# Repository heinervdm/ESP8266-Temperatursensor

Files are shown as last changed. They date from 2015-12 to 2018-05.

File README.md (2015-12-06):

# ESP8266-Temperatursensor
Wifi temperature sensor based on the Espressif ESP8266 Wifi module and the Dallas DS18X20 temperature sensor

For this project it is assumed, that the ESP8266 is configured for deep sleep. For e.g. ESP-01 one needs to patch to PCB, for ESP-03 one has to close the solder jumper neer pin 8.

To compile you have to adjust the paths in the Makefile and copy user_config.h.template to user_config.h and adjust the defines inside.
I'm using a hardcoded IP address because the DNS was not working very well for me and therefore consumes to much power.

The Firmware will read all connected DS18X20 sensors (A define in user_config.h determines the maximum amount of sensors) and will call a the path: /index.php?value[]=...&uid[]=...&... with the read temperature and the uid of the corresponding sensor, as well as the current supply voltage of the ESP8266 module and it's mac address as uid.

# This is based on the following projects:

DS18X20 readout: http://siwawi.bauing.uni-kl.de/avr_projects/tempsensor/

Makefile & user_main structure: https://github.com/esp8266/source-code-examples

ESP8266 eagle footprint: https://github.com/wvanvlaenderen/ESP8266-Eagle_Library

Javascript plotting: https://github.com/dima117/Chart.Scatter

BMP180 readout: https://github.com/reaper7/esp8266_i2c_bmp180

DHT11/22 readout: https://github.com/mathew-hall/esp8266-dht

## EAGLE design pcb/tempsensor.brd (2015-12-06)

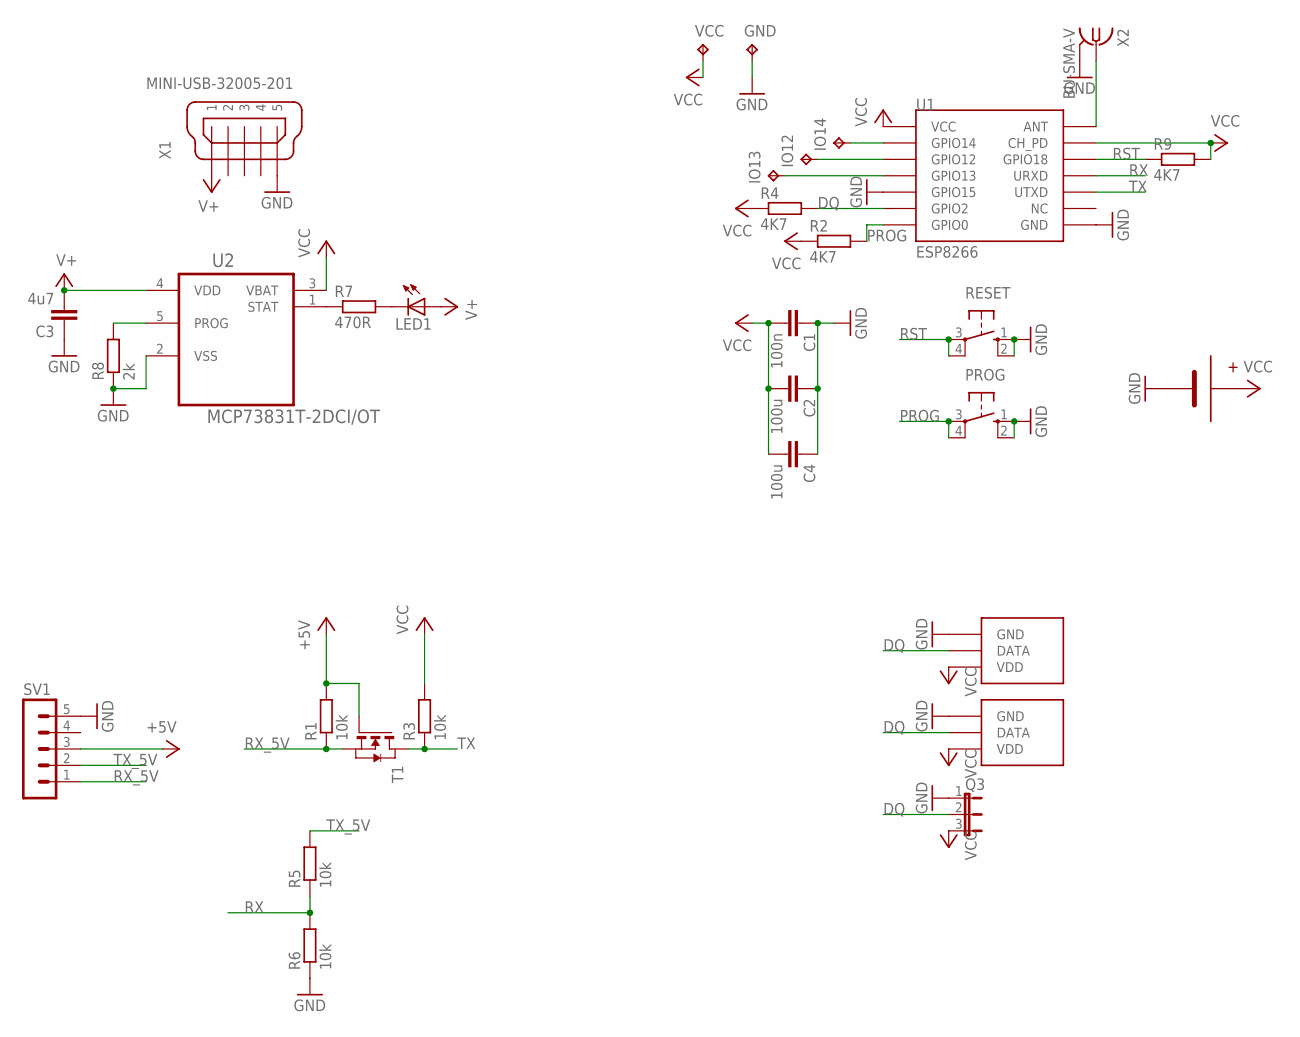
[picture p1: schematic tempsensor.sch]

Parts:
C1: 100n; C0805
C2, C4: 100u; C1206
C3: 4u7; C0805
GND: TPPAD1-13; P1-13
IO12, IO13, IO14: TPPAD1-13; P1-13
LED1: LEDCHIPLED_0805; CHIPLED_0805
PROG: 10-XX; B3F-10XX
Q1: DS18X20TO92; TO92
Q2: DS18X20SO-8; SO08WIDE
Q3: JP2E; JP2
R1, R3, R5, R6: 10k; M0805
R2, R4, R9: 4K7; M0805
R7: 470R; M0805
R8: 2k; M0805
RESET: 10-XX; B3F-10XX
SV1: MA05-1
T1: NMOSSOT23; SOT-23
U1: ESP8266; ESP-03
U2: MCP73831T-2DCI/OT; SOT95P270X145-5N
U$2: 18650-BATTERHOLDERHA1X18650; HA1X18650
VCC: TPPAD1-13; P1-13
X1: MINI-USB-32005-201; 32005-201
X2: BU-SMA-V

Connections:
+5V: R1.2, SV1.3, T1.3 (G)
DQ: Q1.2 (DATA), Q2.4 (DATA), Q3.2, R4.2, U1.GPIO2
GND: C1.1, C2.1, C3.1, C4.1, GND.TP, PROG.1 (S), PROG.2 (S1), Q1.3 (GND), Q2.5 (GND), Q3.1, R6.1, R8.1, RESET.1 (S), RESET.2 (S1), SV1.5, U1.GND, U1.GPIO15, U2.2 (VSS), U$2.P$1, X1.5, X2.2, X2.3 (2), X2.4 (2), X2.5 (2)
unnamed: R7.1, U2.1 (STAT)
unnamed: IO13.TP, U1.GPIO13
unnamed: IO12.TP, U1.GPIO12
unnamed: IO14.TP, U1.GPIO14
unnamed: LED1.C, R7.2
unnamed: R8.2, U2.5 (PROG)
unnamed: U1.ANT, X2.1
PROG: PROG.3, PROG.4 (P1), R2.2, U1.GPIO0
RST: R9.1, RESET.3, RESET.4 (P1), U1.GPIO18
RX: R5.1, R6.2, U1.URXD
RX_5V: R1.1, SV1.1, T1.2 (S)
TX: R3.1, T1.1 (D), U1.UTXD
TX_5V: R5.2, SV1.2
V+: C3.2, LED1.A, U2.4 (VDD), X1.1
VCC: C1.2, C2.2, C4.2, Q1.1 (VDD), Q2.3 (VDD), Q3.3, R2.1, R3.2, R4.1, R9.2, U1.CH_PD, U1.VCC, U2.3 (VBAT), U$2.P$2, VCC.TP

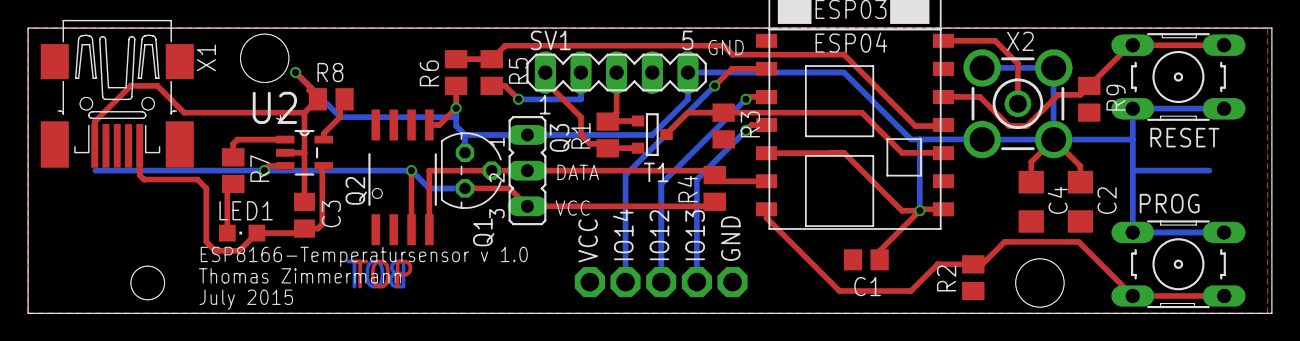
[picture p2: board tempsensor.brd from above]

Board: 2 copper layers, 88.6 x 20.3 mm, 31 parts (1 on the bottom side), 18 nets.

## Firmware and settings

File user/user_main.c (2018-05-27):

#include "ets_sys.h"
#include "osapi.h"
#include "gpio.h"
#include "os_type.h"
#include "user_config.h"
#include "user_interface.h"
#include "stdout.h"
#include "espmissingincludes.h"
#include "espconn.h"
#include "ip_addr.h"
#include "mem.h"

#include "ds18x20.h"
#include "onewire.h"

#ifdef READ_BMP
#include "i2c.h"
#include "i2c_bmp180.h"
#endif

#ifdef READ_DHT
#include "dht.h"
#endif

#ifdef READ_ADS1115
#include "i2c_ads1115.h"
#endif

// #define user_procTaskPrio        0
// #define user_procTaskQueueLen    1

uint8_t gSensorIDs[MAXSENSORS][OW_ROMCODE_SIZE];
// os_event_t    user_procTaskQueue[user_procTaskQueueLen];
static os_timer_t fail_timer;

unsigned char *default_certificate;
unsigned int default_certificate_len = 0;
unsigned char *default_private_key;
unsigned int default_private_key_len = 0;

void ICACHE_FLASH_ATTR getHexStr(char *buf, uint8_t *arr, uint8_t size) {
	uint8_t i=0;
	for (;i<size;i++) {
		uint8_t b = (arr[i] >> 4) & 0x0F;
		if (b > 9) {
			b += 'A'-10;
		}
		else {
			b+= '0';
		}
		buf[i*2]=b;
		b = (arr[i]) & 0x0F;
		if (b > 9) {
			b += 'A'-10;
		}
		else {
			b+= '0';
		}
		buf[i*2+1]=b;
	}
	buf[size*2] = '\0';
}

static uint8_t ICACHE_FLASH_ATTR search_sensors(void) {
	uint8_t i;
	uint8_t id[OW_ROMCODE_SIZE];
	uint8_t diff, nSensors;

	os_printf("Scanning Bus for DS18X20\n");

	ow_reset();

	nSensors = 0;

	diff = OW_SEARCH_FIRST;
	while ( diff != OW_LAST_DEVICE && nSensors < MAXSENSORS ) {
		DS18X20_find_sensor( &diff, &id[0] );

		if( diff == OW_PRESENCE_ERR ) {
			os_printf( "No Sensor found\n" );
			break;
		}

		if( diff == OW_DATA_ERR ) {
			os_printf( "Bus Error\n" );
			break;
		}

		for ( i=0; i < OW_ROMCODE_SIZE; i++ )
			gSensorIDs[nSensors][i] = id[i];

		nSensors++;
	}

	return nSensors;
}

int32_t ICACHE_FLASH_ATTR getTemperature(uint8_t sensor) {
	int32_t temp;

	if ( DS18X20_start_meas( DS18X20_POWER_EXTERN, &gSensorIDs[sensor][0] ) == DS18X20_OK ) {
		for (uint16 i = 0; i < DS18B20_TCONV_12BIT; i++) {
			os_delay_us(1000);
		}
		if ( DS18X20_read_maxres( &gSensorIDs[sensor][0], &temp) != DS18X20_OK ) {
			os_printf("DS18X20: crc error\n");
		}
	}
	else {
		os_printf("DS18X20: failed (short circuit?)");
	}
	char buf[OW_ROMCODE_SIZE*2];
	getHexStr(&buf[0], &gSensorIDs[sensor][0], OW_ROMCODE_SIZE);
	os_printf("Sensor: %d, Temperature: %d, ID: %s\n", sensor, temp, buf);

	return temp;
}

static void ICACHE_FLASH_ATTR disconnect_callback(void * arg) {
	struct espconn *conn = (struct espconn *)arg;
	
	if(conn != NULL) {
		if(conn->proto.tcp != NULL) {
			os_free(conn->proto.tcp);
		}
		os_free(conn);
	}

	// No Wifi after wake up, we will start it manually
// 	system_deep_sleep_set_option(4);
	system_deep_sleep(1000*1000*60*5);
}

static void ICACHE_FLASH_ATTR receive_callback(void * arg, char * buf, unsigned short len) {
	buf[len-1] = 0;
	os_printf("%s", buf);
}

static void ICACHE_FLASH_ATTR sent_callback(void * arg) {
	os_delay_us(1);
}

static void ICACHE_FLASH_ATTR error_callback(void *arg, sint8 errType) {
	disconnect_callback(arg);
}

static void ICACHE_FLASH_ATTR connect_callback(void * arg) {
	struct espconn * conn = (struct espconn *)arg;
	espconn_regist_recvcb(conn, receive_callback);
	espconn_regist_sentcb(conn, sent_callback);
	os_delay_us(1);

	char macstr[2*6+2];
	uint8_t mac[6];
	wifi_get_macaddr(STATION_IF,&mac[0]);
	getHexStr(&macstr[0],&mac[0],6);
	os_printf("Got MAC addr: %s\n", macstr);

	char buf1[(MAXSENSORS+5)*50];
#ifdef READ_1W
	uint8_t n = search_sensors();
	char buf2[50];
	char uid[OW_ROMCODE_SIZE*2+2];
	for (uint8_t i = 0; i < n;i++) {
		int32_t temp = getTemperature(i);
		getHexStr(&uid[0],&gSensorIDs[i][0],OW_ROMCODE_SIZE);
		os_sprintf(buf2,"&value[]=%d.%04d&uid[]=%s",temp/10000,temp%10000,uid);
		os_strcat(buf1, buf2);
		os_delay_us(1);
	}
#endif
#ifdef READ_BMP
i2c_init();
bool ret = BMP180_Init();
if (ret == 1) {
	char buf2[50];
	uint32_t pressure = BMP180_GetVal(GET_BMP_REAL_PRESSURE);
	os_sprintf(buf2,"&value[]=%d.%02d&uid[]=%s%s",pressure/100,pressure%100,macstr,"/pres");
	os_strcat(buf1, buf2);
	os_delay_us(1);
	uint32_t temperature = BMP180_GetVal(GET_BMP_TEMPERATURE);
	os_sprintf(buf2,"&value[]=%d.%01d&uid[]=%s%s",temperature/10,temperature%10,macstr,"/prestemp");
	os_strcat(buf1, buf2);
	os_delay_us(1);
	uint32_t relpressure = BMP180_GetVal(GET_BMP_RELATIVE_PRESSURE);
	os_sprintf(buf2,"&value[]=%d.%02d&uid[]=%s%s",relpressure/100,relpressure%100,macstr,"/presrel");
	os_strcat(buf1, buf2);
	os_delay_us(1);
} else {
	os_printf("BMP180: init couldn't read version register.\n");
}
#endif
#ifdef READ_DHT
	DHTInit(DHT_TYPE,0);
	struct sensor_reading* result = readDHT(1);
	if (result->success == 1) {
		char buf2[50];
		os_sprintf(buf2,"&value[]=%d&uid[]=%s%s",(int)(result->temperature),macstr,"/humiditytemp");
		os_strcat(buf1, buf2);
		os_delay_us(1);
		os_sprintf(buf2,"&value[]=%d&uid[]=%s%s",(int)(result->humidity),macstr,"/humidity");
		os_strcat(buf1, buf2);
		os_delay_us(1);
	}
#endif
#ifdef READ_ADS1115
	ADS1115_init();
	uint16_t adsres = ADS1115_readRawValue();
	{
		char buf2[50];
		os_sprintf(buf2,"&value[]=%ul&uid[]=%s%s",adsres,macstr,"/ph");
		os_strcat(buf1, buf2);
		os_delay_us(1);
	}
#endif
	float v = readvdd33();
// 	float v = system_get_vdd33();
	v /= 1024.;
	os_printf("Got power reading: %d.%02d\n", (int)v, (int)((v-(int)v)*100));
	if (v < 3) {
		// I don't know if i can really shut it off this way but it's the best way i've found.
		os_printf("Truning off to protect the battery from exhaustive discharge\n");
		system_deep_sleep(0);
	}
	os_delay_us(1);

	char buf[400+MAXSENSORS*50];
	int len = os_sprintf(buf,
						"GET /index.php?uid[]=%s&value[]=%d.%02d%s HTTP/1.1\r\n"
						"Host: " HOSTNAME ":%d\r\n"
						"Connection: close\r\n"
						"User-Agent: ESP8266\r\n"
						EXTRA_HEADER "\r\n",
					macstr, (int)v, (int)((v-(int)v)*100), buf1, PORT);
	espconn_sent(conn, (uint8_t *)buf, len);
}

static void ICACHE_FLASH_ATTR fail_timerfunc(void *arg) {
	os_printf("Connect seems to have failed. Going to sleep and trying again in 5 minutes.\n");
	system_deep_sleep(1000*1000*60*5);
}

static void ICACHE_FLASH_ATTR some_timerfunc(void *arg) {
	ip_addr_t addr;
	IPADDR(&addr);

	struct espconn * conn = (struct espconn *)os_malloc(sizeof(struct espconn));
	conn->type = ESPCONN_TCP;
	conn->state = ESPCONN_NONE;
	conn->proto.tcp = (esp_tcp *)os_malloc(sizeof(esp_tcp));
	conn->proto.tcp->local_port = espconn_port();
	conn->proto.tcp->remote_port = 80;
	
	os_memcpy(conn->proto.tcp->remote_ip, &addr, 4);

	espconn_regist_connectcb(conn, connect_callback);
	espconn_regist_disconcb(conn, disconnect_callback);
	espconn_regist_reconcb(conn, error_callback);
	espconn_connect(conn);
}


void ICACHE_FLASH_ATTR wifi_handle_event_cb(System_Event_t *evt) {
	os_printf("event %x\n", evt->event);
	switch (evt->event) {
		case EVENT_STAMODE_CONNECTED:
			os_printf("connect to ssid %s, channel %d\n",
					  evt->event_info.connected.ssid,
			 evt->event_info.connected.channel);
			break;
		case EVENT_STAMODE_DISCONNECTED:
			os_printf("disconnect from ssid %s, reason %d\n",
					  evt->event_info.disconnected.ssid,
			 evt->event_info.disconnected.reason);
			break;
		case EVENT_STAMODE_AUTHMODE_CHANGE:
			os_printf("mode: %d -> %d\n",
					  evt->event_info.auth_change.old_mode,
			 evt->event_info.auth_change.new_mode);
			break;
		case EVENT_STAMODE_GOT_IP:
			// Connection done, disable fail timer
			os_timer_disarm(&fail_timer);
			os_printf("ip:" IPSTR ",mask:" IPSTR ",gw:" IPSTR,
					  IP2STR(&evt->event_info.got_ip.ip),
					  IP2STR(&evt->event_info.got_ip.mask),
					  IP2STR(&evt->event_info.got_ip.gw));
			os_printf("\n");

			os_delay_us(1);
			some_timerfunc(NULL);
			break;
		default:
			break;
	}
}

void ICACHE_FLASH_ATTR init_done(void) {
	os_printf("Init done!\n");

	// Start fail timer, if we have no ip within 10 seconds, go to sleep again
	os_timer_disarm(&fail_timer);
	os_timer_setfn(&fail_timer, (os_timer_func_t *)fail_timerfunc, NULL);
	os_timer_arm(&fail_timer, 1000*10, 0);

	char ssid[32] = SSID;
	char password[64] = SSID_PASSWORD;
	struct station_config stationConf;
	// Set station mode
	wifi_set_opmode(STATION_MODE);

	// Don't check the mac addr
	stationConf.bssid_set = 0; 
	// Set ap settings
	os_memcpy(&stationConf.ssid, ssid, 32);
	os_memcpy(&stationConf.password, password, 64);
	wifi_station_set_config(&stationConf);
	wifi_station_disconnect();
	wifi_set_event_handler_cb(&wifi_handle_event_cb);
	os_printf("Connecting to Wifi\n");
	wifi_station_connect();
}

//Init function 
void ICACHE_FLASH_ATTR user_init() {
	stdoutInit();
	system_init_done_cb(init_done);
}

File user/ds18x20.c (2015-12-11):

/*********************************************************************************
Title:    DS18X20-Functions via One-Wire-Bus
Author:   Martin Thomas <eversmith@heizung-thomas.de>   
          http://www.siwawi.arubi.uni-kl.de/avr-projects
Software: avr-gcc 4.3.3 / avr-libc 1.6.7 (WinAVR 3/2010) 
Hardware: any AVR - tested with ATmega16/ATmega32/ATmega324P and 3 DS18B20

ported to esp8266 by Thomas Zimmermann (bugs(at)vdm-design.de)

Partly based on code from Peter Dannegger and others.

changelog:
20041124 - Extended measurements for DS18(S)20 contributed by Carsten Foss (CFO)
200502xx - function DS18X20_read_meas_single
20050310 - DS18x20 EEPROM functions (can be disabled to save flash-memory)
           (DS18X20_EEPROMSUPPORT in ds18x20.h)
20100625 - removed inner returns, added static function for read scratchpad
         . replaced full-celcius and fractbit method with decicelsius
           and maxres (degreeCelsius*10e-4) functions, renamed eeprom-functions,
           delay in recall_e2 replaced by timeout-handling
20100714 - ow_command_skip_last_recovery used for parasite-powerd devices so the
           strong pull-up can be enabled in time even with longer OW recovery times
20110209 - fix in DS18X20_format_from_maxres() by Marian Kulesza
2015ß719 - ported to ESP8266
**********************************************************************************/

#include "ds18x20.h"
#include "onewire.h"
#include "crc8.h"
#include "ets_sys.h"
#include "espmissingincludes.h"
#include "osapi.h"
#include "os_type.h"
#include "user_interface.h"
#include "stdout.h"

/*----------- start of "debug-functions" ---------------*/

#if DS18X20_VERBOSE
#if (!DS18X20_DECICELSIUS)
#error "DS18X20_DECICELSIUS must be enabled for verbose-mode"
#endif

static int16_t DS18X20_rawo_decicelsius( uint8_t fc, uint8_t sp[] );

char*  ICACHE_FLASH_ATTR itoa(int i, char b[])   // Convert Integer to ASCII!!
{
	char const digit[] = "0123456789";
	char* p = b;
	if(i<0){
		*p++ = '-';
		i *= -1;
	}
	int shifter = i;
	do{ //Move to where representation ends
		++p;
		shifter = shifter/10;
	}
	while(shifter);
	*p = '\0';
	do{ //Move back, inserting digits as u go
		*--p = digit[i%10];
		i = i/10;
	}
	while(i);
	return b;
}

void ICACHE_FLASH_ATTR DS18X20_show_id_uart( uint8_t *id, size_t n ) 
{
	size_t i;

	for( i = 0; i < n; i++ ) {
		if ( i == 0 ) { os_printf( "FC:" ); }
		else if ( i == n-1 ) { os_printf( "CRC:" ); }
		if ( i == 1 ) { os_printf( "SN: " ); }
		os_printf("%x",(id[i]));
		os_printf(" ");
		if ( i == 0 ) {
			if ( id[0] == DS18S20_FAMILY_CODE ) { os_printf ("(18S)"); }
			else if ( id[0] == DS18B20_FAMILY_CODE ) { os_printf ("(18B)"); }
			else if ( id[0] == DS1822_FAMILY_CODE ) { os_printf ("(22)"); }
			else { os_printf("( ? )"); }
		}
	}
	if ( crc8( id, OW_ROMCODE_SIZE) )
		os_printf( " CRC FAIL " );
	else 
		os_printf( " CRC O.K. " );
}

static void ICACHE_FLASH_ATTR show_sp_uart( uint8_t *sp, size_t n ) 
{
	size_t i;

	os_printf( "SP:" );
	for( i = 0; i < n; i++ ) {
		if ( i == n-1 ) { os_printf( "CRC:" ); }
		os_printf("%x",(sp[i]));
		os_printf(" ");
	}
}

/* 
   convert raw value from DS18x20 to Celsius
   input is: 
   - familycode fc (0x10/0x28 see header)
   - scratchpad-buffer
   output is:
   - cel full celsius
   - fractions of celsius in millicelsius*(10^-1)/625 (the 4 LS-Bits)
   - subzero =0 positiv / 1 negativ
   always returns  DS18X20_OK
*/
static uint8_t ICACHE_FLASH_ATTR DS18X20_measo_cel( uint8_t fc, uint8_t *sp, 
	uint8_t* subzero, uint8_t* cel, uint8_t* cel_frac_bits) 
{
	uint16_t meas;
	uint8_t  i;
	
	meas = sp[0];  // LSB
	meas |= ( (uint16_t)sp[1] ) << 8; // MSB
	
	//  only work on 12bit-base
	if( fc == DS18S20_FAMILY_CODE ) { // 9 -> 12 bit if 18S20
		/* Extended res. measurements for DS18S20 contributed by Carsten Foss */
		meas &= (uint16_t) 0xfffe;    // Discard LSB, needed for later extended precicion calc
		meas <<= 3;                   // Convert to 12-bit, now degrees are in 1/16 degrees units
		meas += ( 16 - sp[6] ) - 4;   // Add the compensation and remember to subtract 0.25 degree (4/16)
	}
	
	// check for negative 
	if ( meas & 0x8000 )  {
		*subzero=1;      // mark negative
		meas ^= 0xffff;  // convert to positive => (twos complement)++
		meas++;
	}
	else {
		*subzero=0;
	}
	
	// clear undefined bits for B != 12bit
	if ( fc == DS18B20_FAMILY_CODE || fc == DS1822_FAMILY_CODE ) {
		i = sp[DS18B20_CONF_REG];
		if ( (i & DS18B20_12_BIT) == DS18B20_12_BIT ) { ; }
		else if ( (i & DS18B20_11_BIT) == DS18B20_11_BIT ) {
			meas &= ~(DS18B20_11_BIT_UNDF);
		} else if ( (i & DS18B20_10_BIT) == DS18B20_10_BIT ) {
			meas &= ~(DS18B20_10_BIT_UNDF);
		} else { // if ( (i & DS18B20_9_BIT) == DS18B20_9_BIT ) { 
			meas &= ~(DS18B20_9_BIT_UNDF);
		}
	}
	
	*cel  = (uint8_t)(meas >> 4); 
	*cel_frac_bits = (uint8_t)(meas & 0x000F);
	
	return DS18X20_OK;
}

static void ICACHE_FLASH_ATTR DS18X20_uart_putemp(const uint8_t subzero, 
	const uint8_t cel, const uint8_t cel_frac_bits) 
{
	char buffer[sizeof(int)*8+1];
	size_t i;
	
	os_printf("%c",((subzero)?'-':'+'));
	os_printf("%d",(int)cel);
	os_printf(".");
	itoa(cel_frac_bits*DS18X20_FRACCONV,buffer);
	for ( i = 0; i < 4-strlen(buffer); i++ ) {
		os_printf("0");
	}
	os_printf("%s",(buffer));
	os_printf("°C");
}
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

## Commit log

2015-07-19 Commit inital version
    [tempsensor.brd, tempsensor.sch]
2015-07-19 Update PCB
    [tempsensor.brd, tempsensor.sch]
2015-07-19 Update PCB: Add lipo charging circuit based on mcp73831 and Reset und Program buttons
    [tempsensor.brd, tempsensor.sch]
2015-07-19 PCB add library for MCP73831 from farnell
2015-07-19 PCB: add optional pullup resistor for RESET pin, and additional 100u cap for power
    [tempsensor.brd, tempsensor.sch]
2015-08-10 fix zero padding in url call
    [user_main.c]
2015-08-15 Fix Footprint for DS18B20, VCC and GND were swaped
    [tempsensor.brd, tempsensor.sch]
2015-08-15 PCB: increase size of batterholder pads and rotate esp-03 so that it's antenna is no longer shielded
    [tempsensor.brd, tempsensor.sch]
2015-08-16 Don't check for random mac addr, fixes the problem that the ESP ist constantly reconnecting with reason 201
    [user_main.c]
2015-10-03 call deepsleep also when connection failed
    [user_main.c]
2015-12-06 PCB: rename testpoints, add points for VCC and GND, add RP-SMA connector for external antenna
    [tempsensor.brd, tempsensor.sch]
2015-12-06 Add libraries for DHT11/22 humidity sensors and BMP180 pressure sensor
2015-12-06 Add readout for DHT and BMP sensor and make everything configureable in user_config.h
2015-12-12 i2c_bmp180.c: cleanup
2015-12-12 user_main: fix bmp180 readout (i2c_init was missing), scale results to deg C and hPa
    [user_main.c]
2016-01-05 disable wifi after deep sleep und reenable it again by calling wifi_station_connect after system_init is done
2016-01-09 Remove disabling of RF on startup again. Add timer which goes to deep sleep again, if the module is not connected within 10 seconds after wakeup
2016-09-30 Switch from SQLite class to PDO
2018-05-21 Remove additional braket
2018-05-27 Move calibration from ESP to webpage
2018-05-27 Query calibration function from correct table
